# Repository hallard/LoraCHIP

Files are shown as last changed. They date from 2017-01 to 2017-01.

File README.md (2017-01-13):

C.H.I.P. Computer Lora Gateway/Node for RFM95 or RN2483 Modules
===============================================================

This shield is used to hold HopeRF [Lora module][4] or Microchip [RN2483 LoraWan modules][3] Software with $9 [C.H.I.P. Computer][5]. it has just few minimal features. 

This shield can also act as a LoraWAN Node/gateway using this custom dedicated software    
- C.H.I.P. version of [LMIC][9] stack. This LMIC is in progress to works with this shield.

Features
========
- Footprint for RFM92/95/96/98 Lora module or Microchip RN2483 module
- Placement for choosing single Wire, SMA or u-FL Antenna type
- 2 x LED LED for visual indication
- 1 x Switch button (for example to power clean power off CHIP)
- I2C connector to connect 128x64 Oled or I2C sensors
- FTDI connector connected to Uart2 or Uart1 (selectable with a switch)

I'm waiting now for V1.0 boards PCBs.io, so I didn't fully tested them, I will update ASAP.

Detailed Description
====================

Look at the schematics for more informations.

For RFM95 SPI connexion is classic (MOSI/MISO/CLK/CS) is for SPI2 of CHIP Computer.

Only One GPIO needed for DIO0/DIO1/DIO2 (OR made with 3 diodes and one resistor R3) that will make this board fully compatible with current LIMC implementation, even if I've done a software fix which works with no interrupt. Only Needed for Lora modules, if you're using RFM69HCW and and to use IRQ just place D0 and R3.

Detailed Description
====================

On board switch select which Uart goes to FTDI connector (Uart1 or Uart2), RN2483 use CHIP UART2 and leave you UART1 to connect with serial console to CHIP with FTDI cable.

You can also use shield as a standalone RN2483, just plug FTDI connector with decent 3V3 supply, best us to use FTDI cable with 3V3/5V selectable power (select 3V3 of course)

Please look at C.H.I.P. [Hardware documentation][6].

```
CHIP Computer        RN2483
   LCD-D7        <---->  Reset
   LCD-D2 (TXD2) <---->  RXD
   LCD-D3 (RXD2) <---->  TXD

CHIP Computer    RFM95 Module
   CSIPCK   <---->  CS
   CSICK    <---->  CLK
   CSIHSYNC <---->  MOSI
   CSIVSYNC <---->  MISO
   CSID3    <---->  Reset
   DIO0     <---->  CSID0
   DIO1     <---->  CSID1
   DIO2     <---->  CSID2

CHIP Computer   On Board Leds
   LCD-D4  <---->  RED LED
   PWM     <---->  GREEN LED
```

### Schematic  
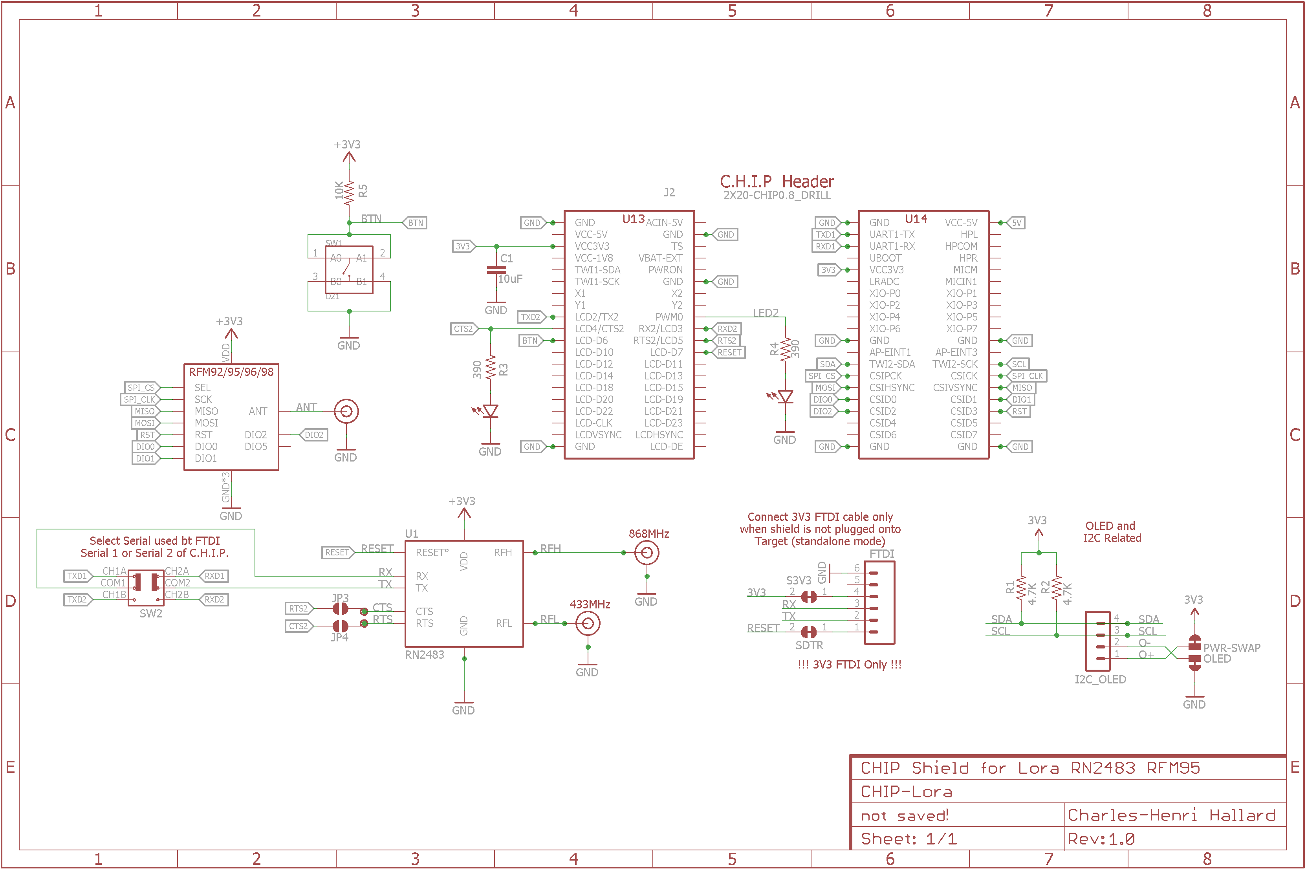
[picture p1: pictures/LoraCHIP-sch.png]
schematic
  

### Boards  
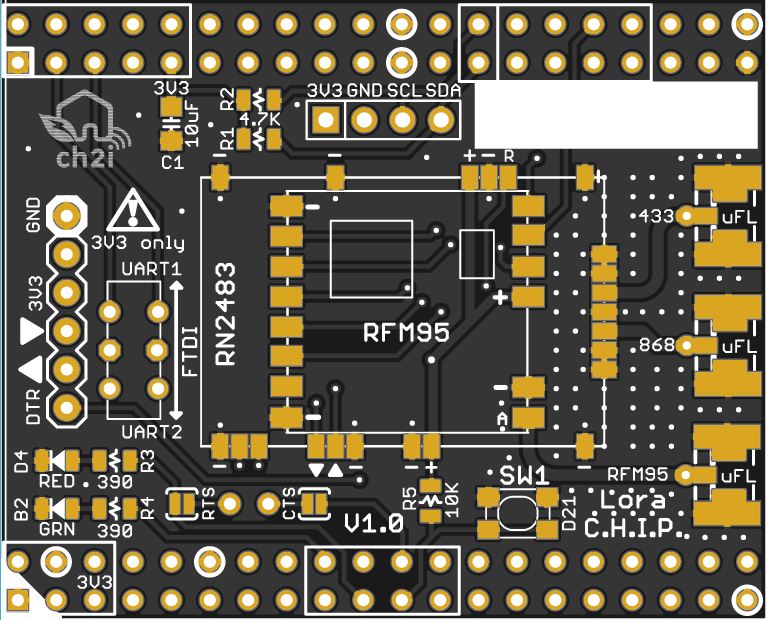
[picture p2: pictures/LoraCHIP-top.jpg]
Top
    

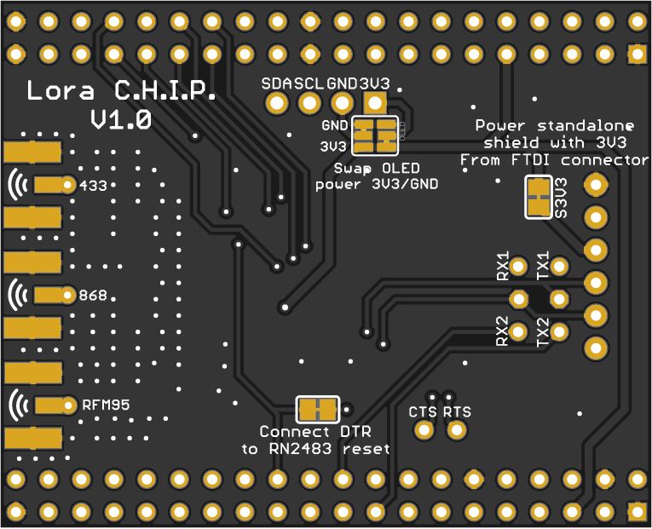
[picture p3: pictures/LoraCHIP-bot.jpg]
Bottom
 

You can order the PCB of this board at [PCBs.io][8]. PCBs.io give me some reward when you order my designed boards from their site. This is pretty good, because I can use these rewards to create and design new boards and order boards for a discounted price and share new boards. So if you don't care about PCB manufacturer please use PCBs.io.

### Assembled boards (V1.0)

TBD

### V1.0 connected to C.H.I.P.

TBD

##License

   

This work is licensed under a [Creative Commons Attribution-NonCommercial 4.0 International License](http://creativecommons.org/licenses/by-nc/4.0/)    
If you want to do commercial stuff with this project, please contact [CH2i company](https://www.ch2i.eu/en#support) so we can organize an simple agreement.

##Misc

See news and other projects on my [blog][2] 

[1]: https://staging.thethingsnetwork.org/wiki/Hardware/Gateways/DIY 
[2]: https://hallard.me
[3]: http://www.microchip.com/wwwproducts/en/RN2483
[4]: http://www.hoperf.com/rf_transceiver/lora/
[5]: https://getchip.com/pages/chip
[6]: https://docs.getchip.com/chip.html#pin-headers
[8]: https://PCBs.io/share/46N5m
[9]: https://github.com/hallard/arduino-lmic/tree/rpi
[13]: https://github.com/hallard/arduino-lmic/blob/rpi/README.md

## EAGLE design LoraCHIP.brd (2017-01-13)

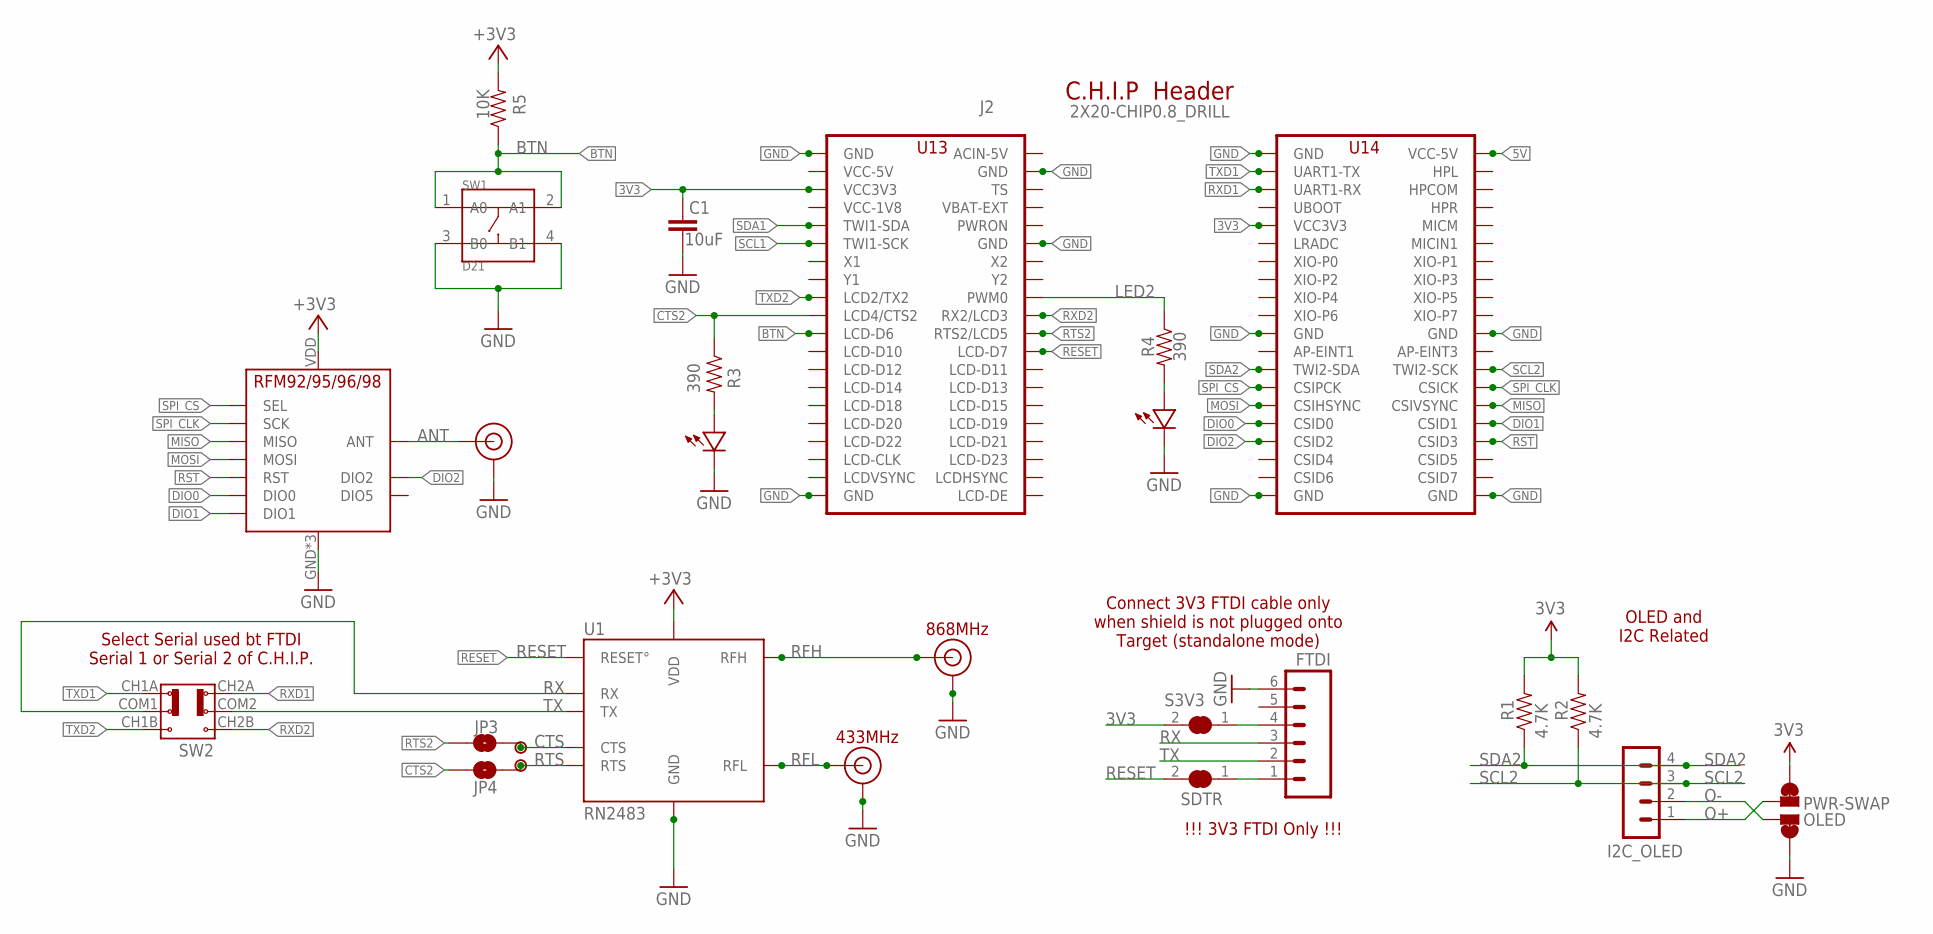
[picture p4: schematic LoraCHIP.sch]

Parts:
C1: 10uF; 0805-CAP-LARGEPADS
FTDI: M06SIP; 1X06
I2C_OLED: CON_HEADER_1X04'SMALL''; M1X4
J2: 2X20-CHIP0.8_DRILL; 2X20CHIP_NOOFFSET-TH_0.8
J$1, J$2, J$3: ANTENNATINY; SMA_UFL_PAD_TINY
JP3: CTS; PAD-JUMPER-2-NO_YES_SILK
JP4: RTS; PAD-JUMPER-2-NO_YES_SILK
OLED: PWR-SWAP; PAD-JUMPER-SWAP
P1, P2: PADSMALL; PAD-SMALL
R1, R2: 4.7K; 0805-RES
R3, R4: 390; 0805-RES
R5: 10K; 0805-RES
S3V3: SOLDERJUMPER_CLOSED; SOLDERJUMPER_CLOSEDWIRE
SDTR: SOLDERJUMPER_CLOSED; SOLDERJUMPER_CLOSEDWIRE
SW1: D21; SW4-SMD-4.2X3.2X2.5MM
SW2: SWITCH-2CH-6P-3010010P1; 6P-2CH-2.54-9.1X3.5X3.2+2H
U1: RN2483; RN2483_NOGPIO
U$1: GRN; 0805-LED
U$3: RED; 0805-LED
U$4: RFM95

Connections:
3V3: C1.2, J2.VCC3V3, J2.VCC3V3@1 (VCC3V3), OLED.4, OLED.44 (4), R1.2, R2.2, R5.2, S3V3.2, U1.VDD, U1.VDD2 (VDD), U$4.VDD (VCC)
5V: J2.VCC5V@1 (VCC-5V)
ANT: J$3.ANT0 (ANT), J$3.ANT1 (ANT), J$3.ANT2 (ANT), U$4.ANT
BTN: J2.LCD-D6, R5.1, SW1.1 (A0), SW1.2 (A1)
CTS: JP3.1, P1.1, U1.UART_CTS (CTS)
CTS2: J2.LCD-D4 (LCD4/CTS2), JP4.2, R3.1
DIO0: J2.CSID0, U$4.DIO0
DIO1: J2.CSID1, U$4.DIO1
DIO2: J2.CSID2, U$4.DIO2
GND: C1.1, FTDI.6, J2.GND@1 (GND), J2.GND@2 (GND), J2.GND@3 (GND), J2.GND@4 (GND), J2.GND@5 (GND), J2.GND@6 (GND), J2.GND@7 (GND), J2.GND@8 (GND), J2.GND@10 (GND), J$1.GND1 (GND), J$1.GND2 (GND), J$1.GND3 (GND), J$1.GND4 (GND), J$1.GND5 (GND), J$1.GND6 (GND), J$2.GND1 (GND), J$2.GND2 (GND), J$2.GND3 (GND), J$2.GND4 (GND), J$2.GND5 (GND), J$2.GND6 (GND), J$3.GND1 (GND), J$3.GND2 (GND), J$3.GND3 (GND), J$3.GND4 (GND), J$3.GND5 (GND), J$3.GND6 (GND), OLED.1, OLED.11 (1), SW1.3 (B0), SW1.4 (B1), U1.GND, U1.GND1 (GND), U1.GND2 (GND), U1.GND3 (GND), U1.GND4 (GND), U1.GND5 (GND), U1.GND6 (GND), U1.GND7 (GND), U1.GND8 (GND), U1.GND9 (GND), U1.GND10 (GND), U1.GND11 (GND), U1.GND12 (GND), U$1.MINUS, U$3.MINUS, U$4.GND, U$4.GND1 (GND), U$4.GND2 (GND)
LD2: R4.2, U$1.PLUS
LED2: J2.PWM0, R4.1
MISO: J2.CSIVSYNC, U$4.MISO
MOSI: J2.CSIHSYNC, U$4.MOSI
unnamed: FTDI.1, SDTR.1
unnamed: FTDI.4, S3V3.1
unnamed: R3.2, U$3.PLUS
O+: I2C_OLED.1, OLED.3
O-: I2C_OLED.2, OLED.2
RESET: J2.LCD-D7, SDTR.2, U1.RESET°
RFH: J$2.ANT0 (ANT), J$2.ANT1 (ANT), J$2.ANT2 (ANT), U1.RFH
RFL: J$1.ANT0 (ANT), J$1.ANT1 (ANT), J$1.ANT2 (ANT), U1.RFL
RST: J2.CSID3, U$4.RST
RTS: JP4.1, P2.1, U1.UART_RTS (RTS)
RTS2: J2.LCD-D5 (RTS2/LCD5), JP3.2
RX: FTDI.3, SW2.COM1, U1.UART_RX (RX)
RXD1: J2.UART1-RX, SW2.CH2A
RXD2: J2.LCD-D3 (RX2/LCD3), SW2.CH2B
SCL1: J2.TWI1-SCK
SCL2: I2C_OLED.3, J2.TWI2-SCK, R2.1
SDA1: J2.TWI1-SDA
SDA2: I2C_OLED.4, J2.TWI2-SDA, R1.1
SPI_CLK: J2.CSICK, U$4.SCK
SPI_CS: J2.CSIPCK, U$4.NSS (SEL)
TX: FTDI.2, SW2.COM2, U1.UART_TX (TX)
TXD1: J2.UART1-TX, SW2.CH1A
TXD2: J2.LCD-D2 (LCD2/TX2), SW2.CH1B
VCC-1V8: J2.VCC1V8 (VCC-1V8)
VCC-5V: J2.VCC5V@0 (VCC-5V)

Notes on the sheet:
C.H.I.P Header
868MHz
433MHz
Connect 3V3 FTDI cable only when shield is not plugged onto Target (standalone mode)
!!! 3V3 FTDI Only !!!
OLED and I2C Related
Select Serial used bt FTDI Serial 1 or Serial 2 of C.H.I.P.

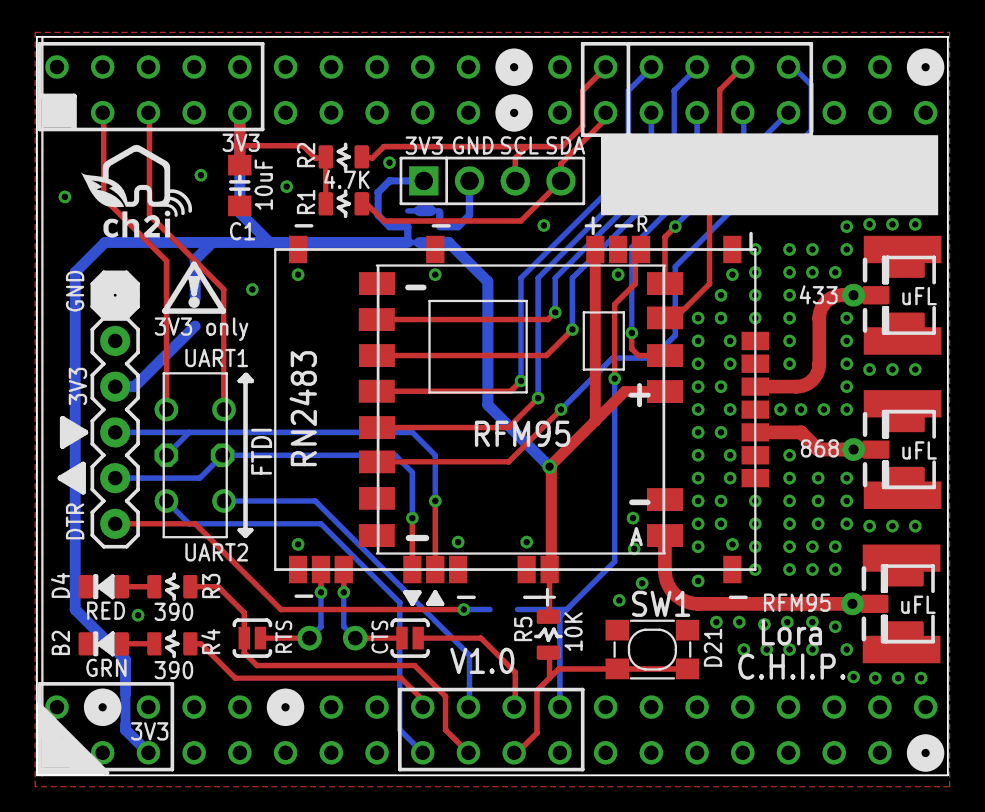
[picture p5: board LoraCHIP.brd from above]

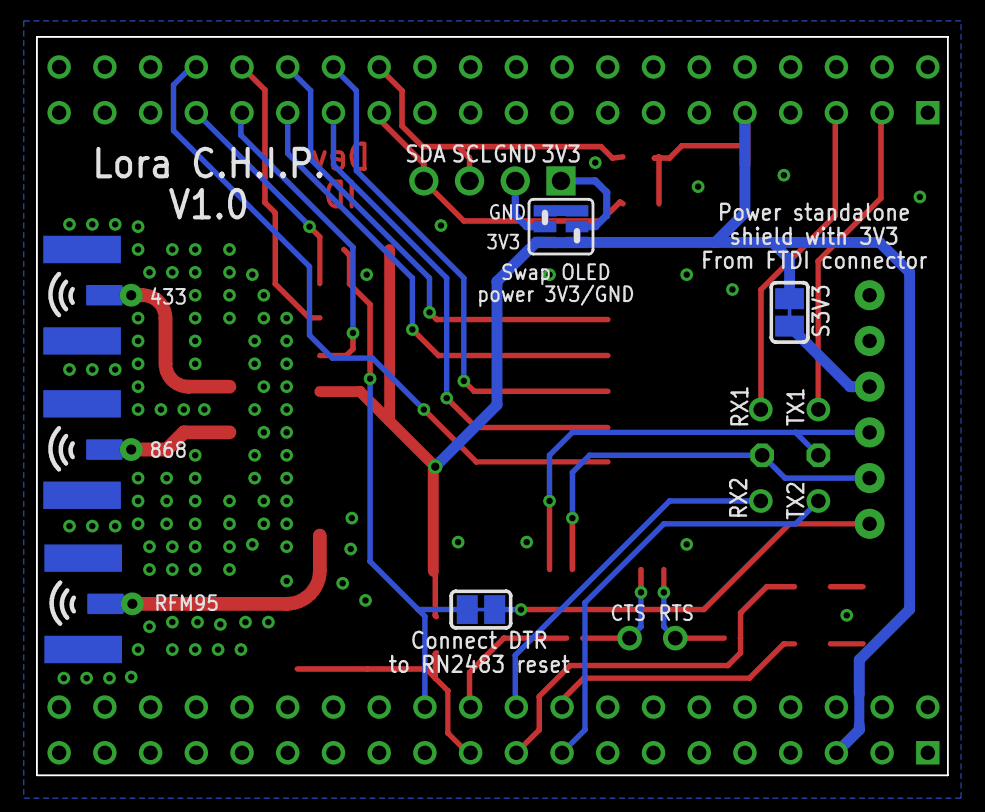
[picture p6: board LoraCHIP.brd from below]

Board: 2 copper layers, 50.6 x 41.0 mm, 26 parts (3 on the bottom side), 34 nets.

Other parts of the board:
U$2: LOGO_C2I_015

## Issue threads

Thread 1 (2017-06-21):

Have you tested the board?

niau, 2017-06-21:
Hi Hallard,

Great work for designing this PCB. Have you actually finally tested it?

If not what could we do in order to do a proper test with it.

Also is there an extra BOM related to getting it working with RFM95?

hallard, 2017-06-23:
Hi tested it with RFM95, I succeded to to talk with it but didn't had time to go further because my LMIC stack for RPI is using BCM2835 library driver that are not on CHIP. The code need to be rewrite to use generic SPI access from any Linux computer.

niau, 2017-07-04:
Hi Hallard,

Interesting may you point me to the pieces that has to be rewritten?
I have some kernel experience, modules and chip also have arrived so can try to contribute here.

hallard, 2017-08-15:
it's on this one [RPI LMIC port](https://github.com/hallard/arduino-lmic/tree/rpi), under rpi/src/raspi
The file is [raspi.cpp](https://github.com/hallard/arduino-lmic/blob/rpi/src/raspi/raspi.cpp)

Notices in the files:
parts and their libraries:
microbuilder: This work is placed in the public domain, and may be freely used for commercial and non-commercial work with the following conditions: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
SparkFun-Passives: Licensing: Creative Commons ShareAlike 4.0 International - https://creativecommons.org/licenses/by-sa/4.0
